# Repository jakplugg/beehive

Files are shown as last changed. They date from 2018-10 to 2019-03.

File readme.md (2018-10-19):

# BeeHive; 

### 8hp version of plaits.

#### PCB redesign by J. Matheson. it works with the same firmware, 

[PRELIM BOM](https://docs.google.com/spreadsheets/d/1ExJeusegeBT_gItCbZ26uzS0rhNw-pVl3f8RWfpthzo/edit?usp=sharing)

8 hp 0603 version of plaits. the only change is added jtag header and "both ways" power as usual.

backer zip passworded until nov 19

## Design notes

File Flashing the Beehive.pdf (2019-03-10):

Instructions on Flashing the Beehive Module

By Jorsh Bee with additional information by Jason Nolan

This tutorial is designed to explain how to flash IC4 on the module (STM32F373CCT6, Cortex M4), and will work on other similar modules using these chips in the Mutable Instruments family, and perhaps others. Other tutorials are available, but this one tries to add more detailed information and links all in one place

In order to use microprocessor-based modules, it is necessary to install a bootloader on the microprocessor and then the firmware (see Links below for everything mentioned in this tutorial). To do this you need a windows computer or a Mac running windows in Bootcamp or using a virtual machine (VM) like Parallels. You also need the STM32 ST-Link utility and software, as well as precompiled bootloader and firmware hex files.

- Connect power cable to you Beehive, but don't turn on your power supply yet.
- Connect the STM32 ST-Link to the Beehive as shown below
- The pins of JP6 from nearest the top of the module top to bottom of the Beehive are GND, SWDIO, SWCLK, and RESET.
- Pins 1 & 19 of the STLink are connected together.
- Pin 20 of the STLlink goes to GND, pin 7 goes to SWDIO, pin 9 goes to SWCLK, and pin 15 goes to Reset.

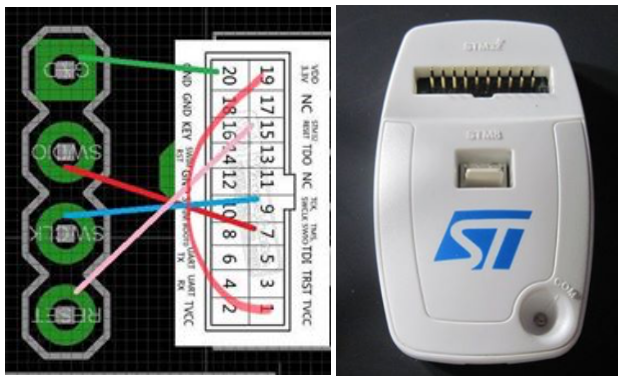
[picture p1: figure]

- Be aware of the orientation of the pins. If you orient your PCB facing you, you can see that on the left side there are the 4 pins (JP6) and the top one is the square one

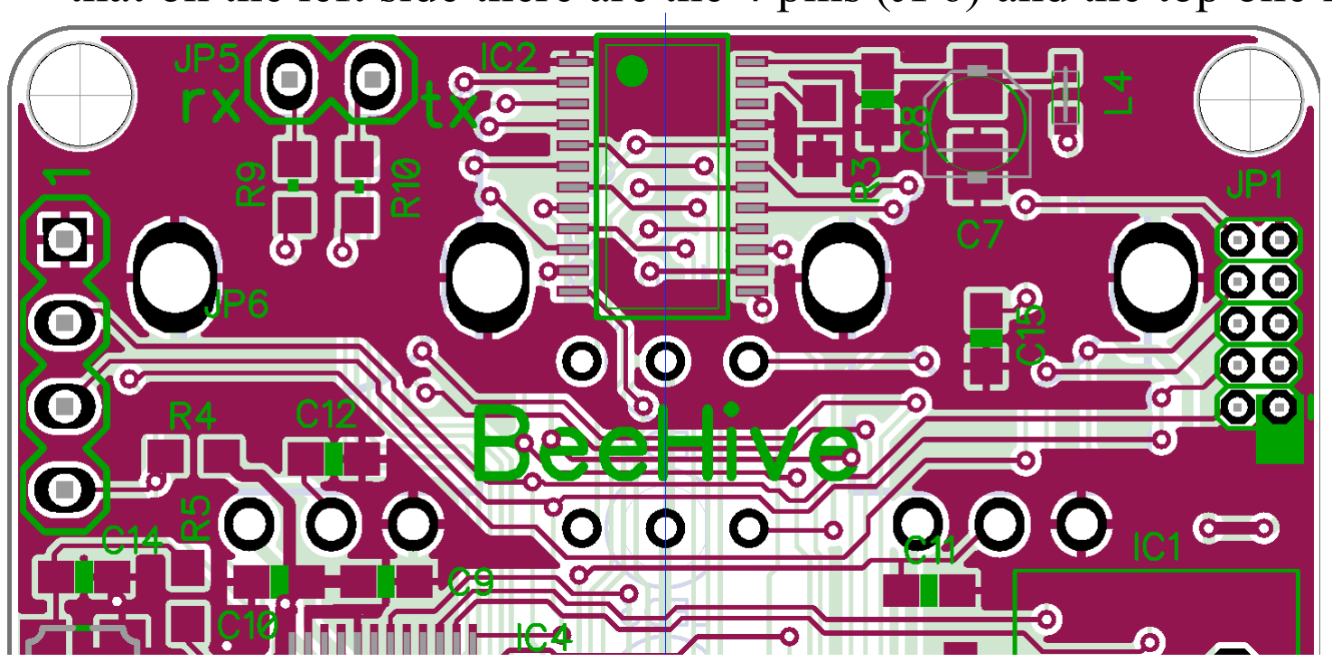
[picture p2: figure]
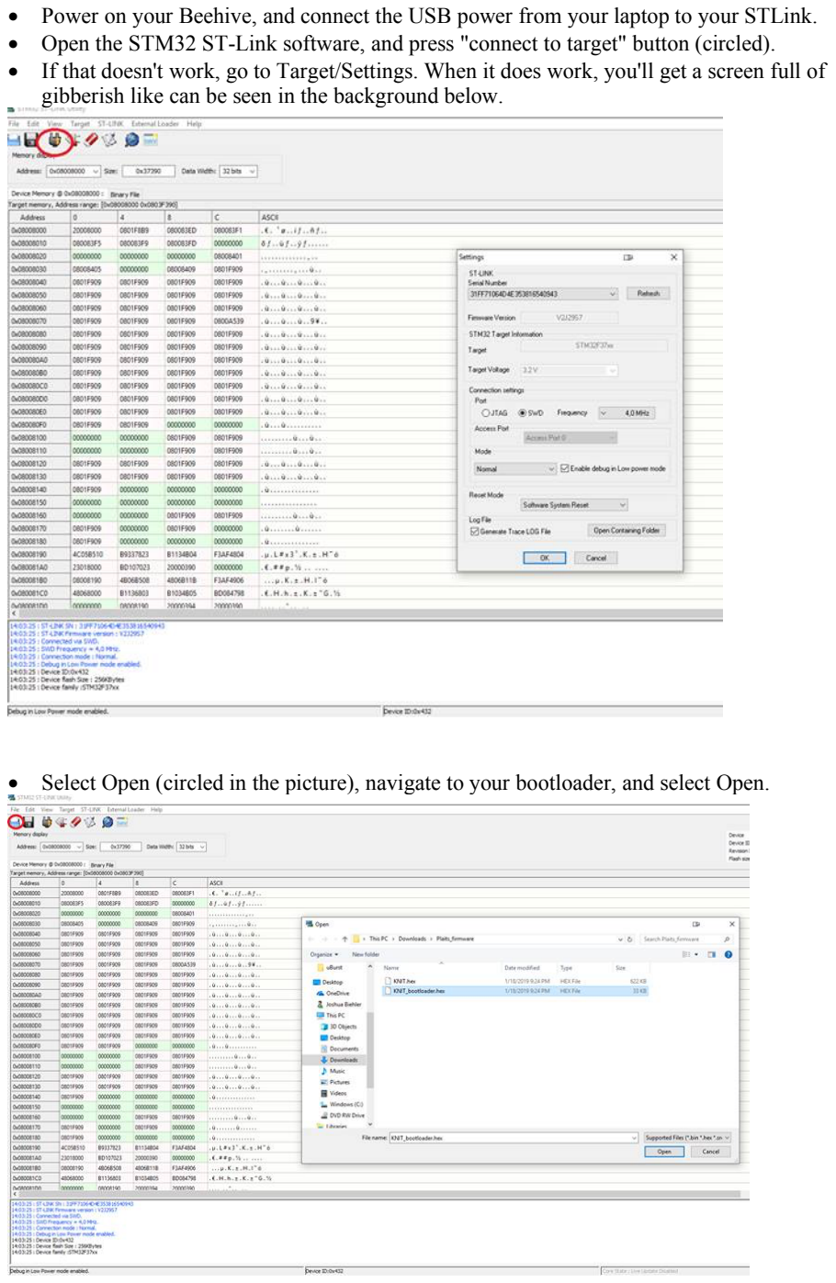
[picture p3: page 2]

- Power on your Beehive, and connect the USB power from your laptop to your STLink.
- Open the STM32 ST-Link software, and press "connect to target" button (circled).
- If that doesn't work, go to Target/Settings. When it does work, you'll get a screen full of gibberish like can be seen in the background below.
- Select Open (circled in the picture), navigate to your bootloader, and select Open.

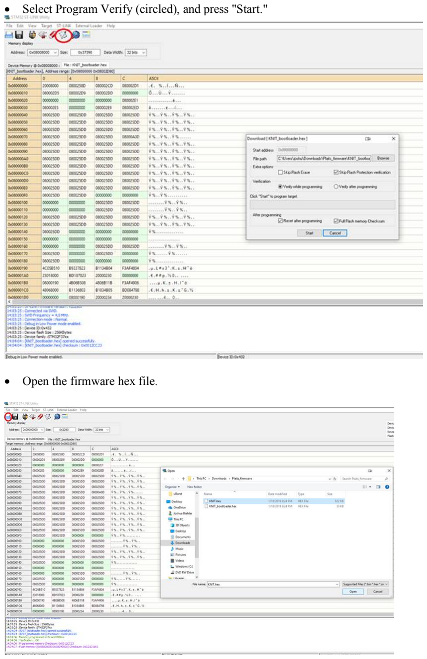
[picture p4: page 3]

- Select Program Verify (circled), and press "Start."
- Open the firmware hex file.

- Select Program Verify and press "Start."

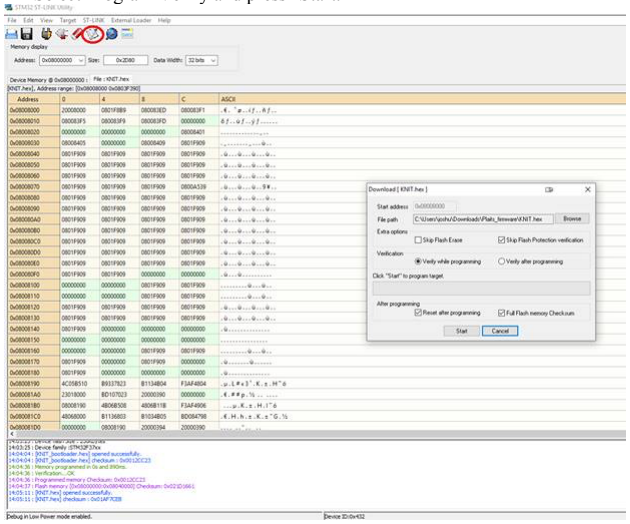
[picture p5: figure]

- You should get a message that says "Verification OK" after programming both the bootloader and the program file.

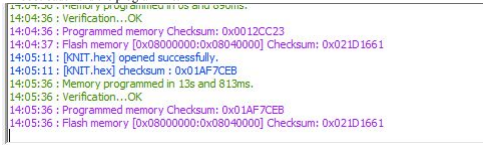
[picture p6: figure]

Once programmed successfully, close out of STM32 ST-Link utility. Then you can power off your module and disconnect the pins from JP6. Calibrate per instructions available in the Mutable Instruments' documentation for Plaits.

Links & Comments
- ST-LINK/V2 hardware can be bought from many vendors and there are cheap knock-offs for a few bucks. You only need the version with the jumper cables.
- STSW-LINK004 is the software, and can be downloaded from https://www.st.com/en/development-tools/stsw-link004.html
- Bootloader and Firmware are on the Antumbra Knit page: http://antumbra.eu/bom/knit/v1-0
- Calibration software can be found on the Mutable Instruments’ Plaits manual page: https://mutable-instruments.net/modules/plaits/manual/ at the bottom.

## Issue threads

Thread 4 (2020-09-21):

PCB manufacturing

zjobra, 2020-09-21:
I've added this board and BOM to PCBHubs for easy manufacturing order
https://pcbhubs.com/newpcb/16007163335f68fe2dabd30

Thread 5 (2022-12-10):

Beehive firmware update via wave file not working

suit4, 2022-12-10:
Hi there,

I am wondering what the problem or my mistake might be, if a firmware update via wave file is nor working.
My Bee Hive works completely fine.
Using any wave file firmware update alway shows the module receiving audio signals in the correct range, but the lower 4 LEDs keep blinking, which actually means, that it does not receive data.

Any idea what might cause this?

jakplugg, 2022-12-11:
It has been tested to work with the new firmware, so it should work. Audio updating is notoriously finicky. Try updating from a different device, for me it would only work from a phone, but not computer.

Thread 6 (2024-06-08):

Flashing the BeeHive - missing firmware and bootloader from the manual

nonszalancki, 2024-06-08:
Hi there,

The Antumbra Knit website mentioned in Flashing the Beehive.pdf doesn't have the firmware and bootloader for download. Any alternatives besides compiling from Mutable Instruments Plaits repo?

jasonnolan, 2024-06-08:
That stuff was available, so I just made up the Flashing the Beehive instructions because it didn't exist. You can google alternative firmware for plaits and there will be stuff. Good luck.

nonszalancki, 2024-06-08:
Case closed. Thank you @jasonnolan for help ;)

Closed 2024-06-08.

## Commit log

2018-10-19 added bOM
2018-10-26 icons disappeared
    moving diptrace file seems to make the graphic image get lost, it is
    provided just in case. (icons.tif)
2018-11-21 no more password
    opened passworded zip
    [beehive.DRL, beehive.GBL, beehive.GBO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]
